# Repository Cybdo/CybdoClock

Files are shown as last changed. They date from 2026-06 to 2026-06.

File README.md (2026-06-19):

# CybdoClock!!

14 by 14 letter word clock / calendar / whatever, powered by esp32-c6!

27 past 5

Word clocks are arguably better and cooler than normal analog or digital clocks, but they are way too expensive comercially for a decent product, and even then there's not much customisation to it (the only one i could find was over 1000 dollars and could only show the time in 5 minute increments). CybdoClock was made to be able to show time down to the minute, in multiple formats, all while being customisable and allowing for different uses. The face plate can be swapped to show different languages or formats, and a calendar faceplate is coming soon!

# zine page
pdf at `./zine.pdf`


# Features
- native wifi, bluetooth and matter over thread capabilities
- support for custom faceplates with an easy to update firmware dict
- NTP time sync via wifi
- wall-mountable via command strips
- stand included for desktop use

# Assembly

The housing requires 4x M3 screws, as well as 4x M3 heat-set inserts, and 4x 5mm diameter, 2.5mm thick magnets.
Each faceplate also requires 4x 4x 5mm diameter, 2.5mm thick magnets, in the opposite polarity to the housing.
Magnets should be able to friction fit and stay in place, however a drop of superglue can aid in its placement.

# Usage
- flash circuitpython 10 onto the ESP-32 via USB-C.
- Copy the firmware folder onto the CIRCUITPY drive, and create settings.toml using settings.toml.example.
- install all requirements in requirements.txt using `circup install -r requirements.txt`

CybdoClock will now turn on and sync to NTP once connected to a USB power source!

# Firmware
CybdoClock runs off CircuitPython 10.x, and code can be found under `./firmware/`

# Technical Documentation

CybdoClock is powered by a 14x14 LED matrix. NOTE: CybdoClock refreshes vertically, and defaults to left -> right. This is a hardware limitation, and overrides in firmware could cause permanent damage to components.

## Shift Registers

While the provided firmware uses the adafruit library and pins, a custom firmware can interface with the pins by sending the following serial data:

| 0 | 1 | 2 | 3 | 4 | 5 | 6 | 7 | 8 | 9 | 10 | 11 | 12 | 13 | 14 | 15 | 16 | 17 | 18 | 19 | 20 | 21 | 22 | 23 | 24 | 25 | 26 | 27 | 28 | 29 | 30 | 31 |
|---|---|---|---|---|---|---|---|---|---|---|---|---|---|---|---|---|---|---|---|---|---|---|---|---|---|---|---|---|---|---|---|
| Row 14 | Row 13 | Row 12 | Row 11 | Row 10 | Row 9 | Row 8 | NC | Row 7 | Row 6 | Row 5 | Row 4 | Row 3 | Row 2 | Row 1 | NC | Col 14 | Col 13 | Col 12 | Col 11 | Col 10 | Col 9 | Col 8 | NC | Col 7 | Col 6 | Col 5 | Col 4 | Col 3 | Col 2 | Col 1 | NC |
## Schematics

Please note - the net labels for columns and rows do not reflect their physical layouts, nor does the layout of the matrix in the schematic
a pdf can be found at `./schematics.pdf`


## PCB


# Acknowledgements
 - [KiCad](https://www.kicad.org)
 - [Hack Club Fallout](https://fallout.hackclub.com)
 - [pcb2blender](https://github.com/30350n/pcb2blender)
 - [Blender](https://blender.org)
 - [CircuitPython](https://circuitpython.org/)

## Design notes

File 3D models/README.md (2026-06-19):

\# 3D Models

Everything should be able to print without supports, however the housing could turn out better if supports were enabled.

When printing the clock faceplate, pause the print at around 2-3 layers, and place a sheet of Tulle fabric over it, secured with either magnets or glue, and then continue printing. This keeps floating sections of text secured to the faceplate and enhances the legibility of the letters.

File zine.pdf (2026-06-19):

# CybdoClock

# A 14x14 ESP-32 powered word clock!

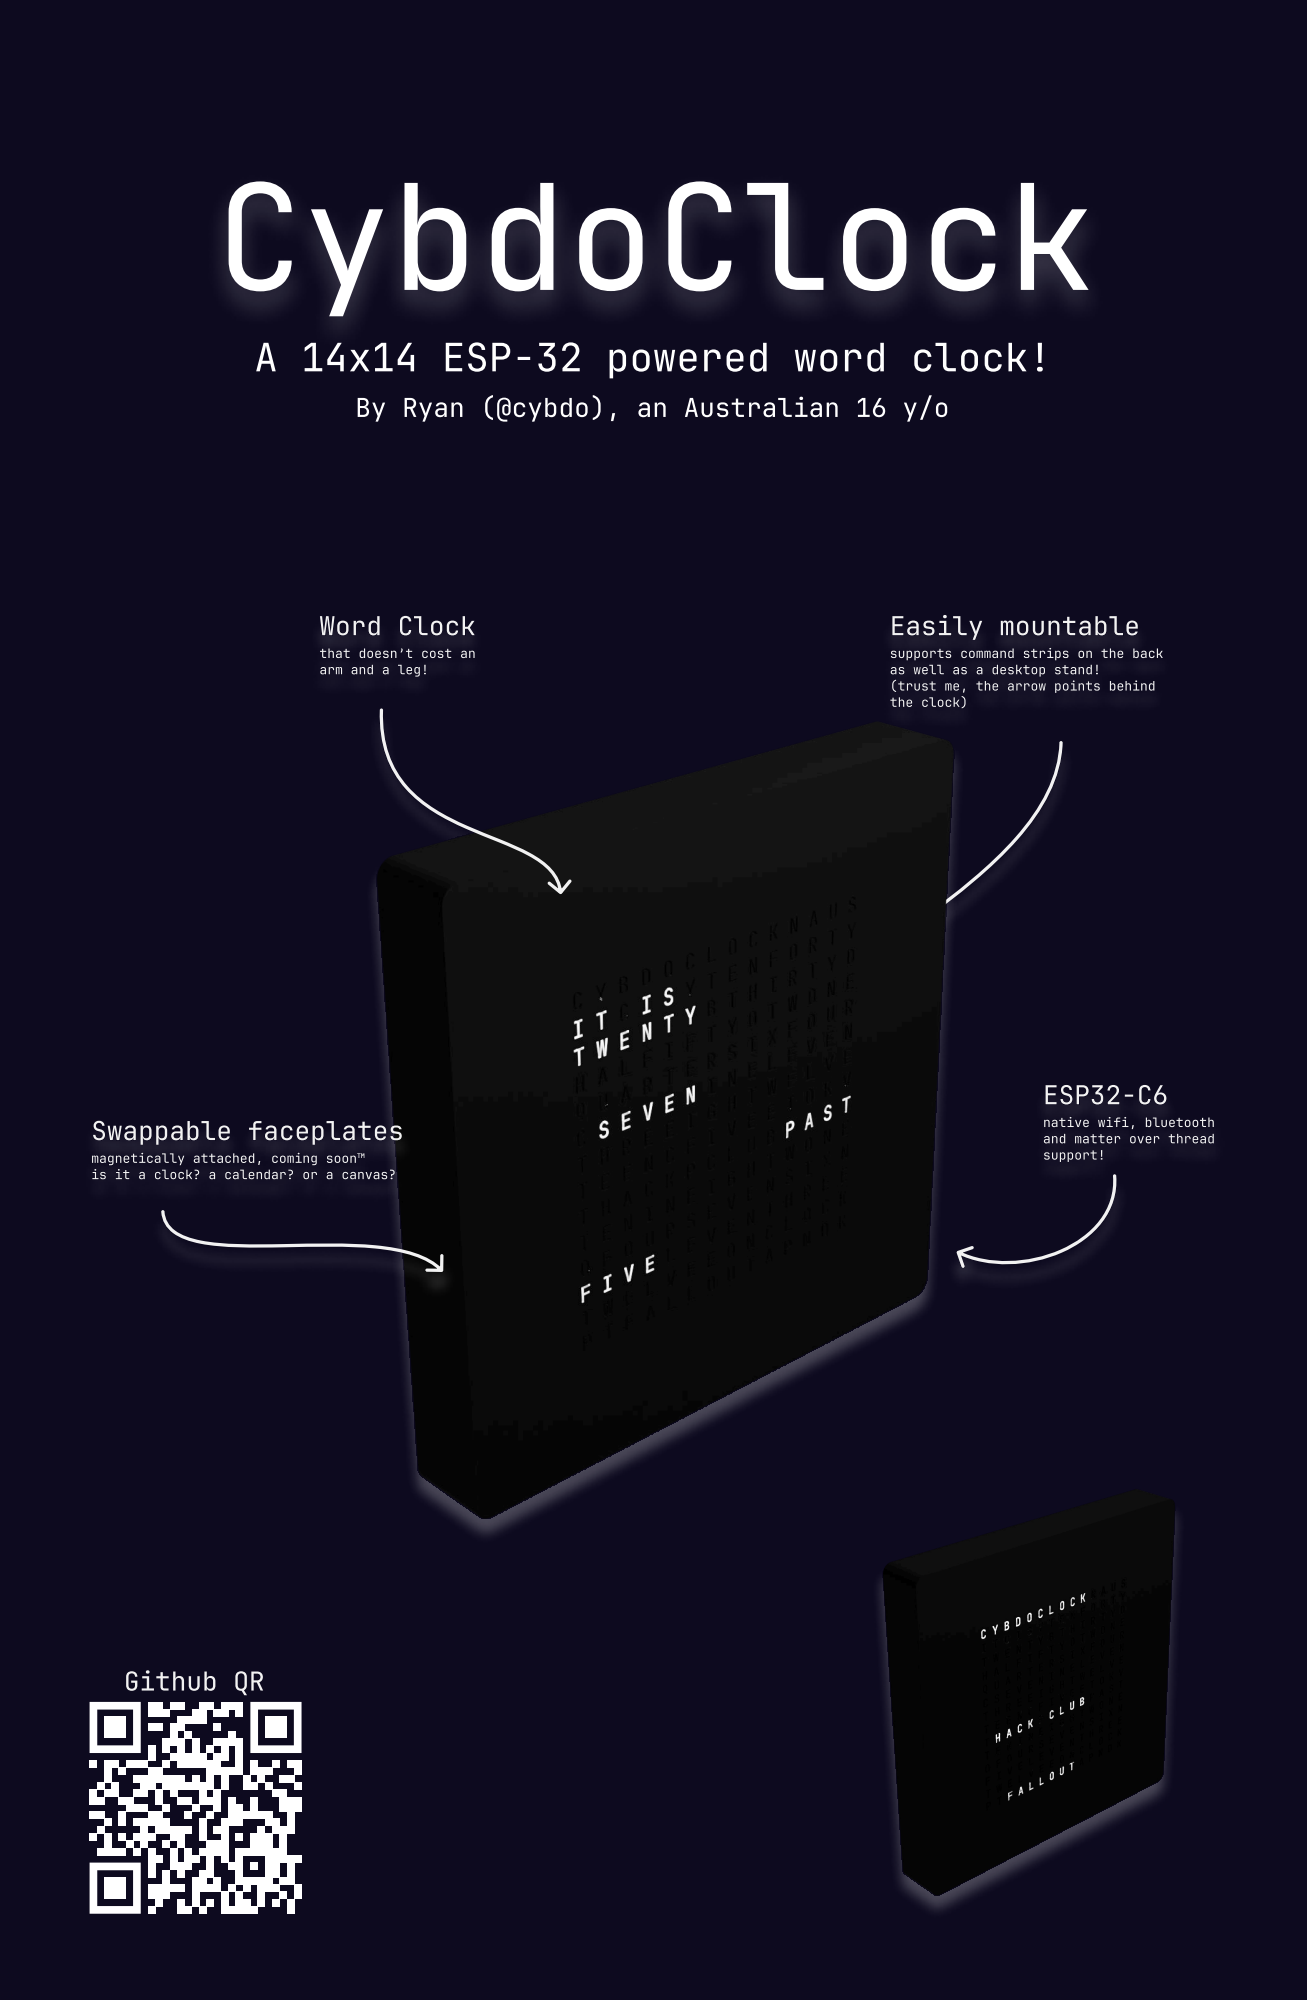
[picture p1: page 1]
Word Clock; Easily mountable; the clock); Swappable faceplates; ESP32-C6; Github QR

By Ryan (@cybdo), an Australian 16 y/o

that doesn’t cost an
arm and a leg!

supports command strips on the back
as well as a desktop stand!
(trust me, the arrow points behind

native wifi, bluetooth

and matter over thread
support!

magnetically attached, coming soon™

is it a clock? a calendar? or a canvas?

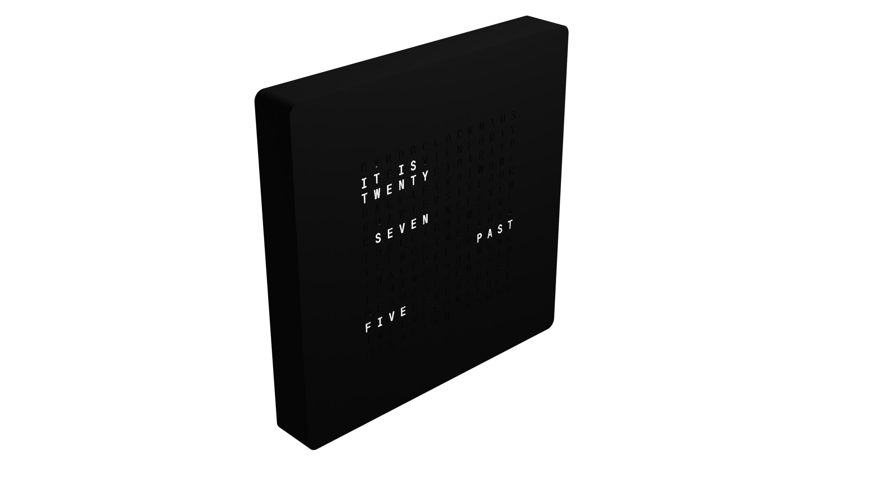
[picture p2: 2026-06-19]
Rendering/27 past 5.png

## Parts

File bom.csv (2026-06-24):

Item | Price ea (USD) | Qty | Price Total (USD) | Link | notes
components | 13.87 | 1 | 13.87 | https://lcsc.com | see lcsc-bom.xls and excl shipping
magnet (5mmx2.5mm) 10pk | 1 | 1 | 1 | https://www.aliexpress.com/item/1005011595343023.html?curPageLogUid=HDLwaCxZ9dYk&utparam-url=scene%3Asearch|query_from%3A|x_object_id%3A1005011595343023|_p_origin_prod%3A
M3 screw 100pcs | 1.25 | 1 | 1.25 | https://www.aliexpress.com/item/32869840993.html
M3 heat set insert | 1 | 1 | 1 | https://www.aliexpress.com/item/1005004870993068.html
Tulle Fabric | 9.81 | 1 | 9.81 | https://www.spotlightstores.com/en-au/p/plain-180-cm-my-special-day-tulle-fabric/BP80599805-black
PCB 5pcs | 25.57 | 1 | 25.57 | https://jlcpcb.com | including shipping
xiao esp-32 c6 | 1 | 1 | 1 | https://www.aliexpress.com/item/1005006987272421.html
 | Total: | 53.5

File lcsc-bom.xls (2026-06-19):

kicad-bom.csv |  |  |  |  |  |  |  |  |  | LCSC BOM Quotation
 |  |  |  |  |  |  |  |  |  | BOM Date Created：19/06/26 10:48:09 |  |  |  | BOM Export Date: 19/06/26 10:52:23 |  |  |  | The matching result is a real-time query result, availability and prices may fluctuate. Backorder items are estimated prices for your reference, please submit "Create Quote" to get the real price. All information is provided "as is" and is subject to change without notice. Any use made of the information provided is without recourse to LCSC and at the user's risk.
 |  |  |  |  |  |  |  |  |  | EST TOTAL :$13.87 |  |  |  | Website：https://www.lcsc.com/bom | https://www.lcsc.com/bom | https://www.lcsc.com/bom | https://www.lcsc.com/bom
Uploaded data |  |  |  |  |  |  |  |  |  | LCSC Matching Results
LCSC# | Mfr. | Mrf# | Description | Package | Value | Customer Part Number | Quantity | Target Price(USD) | Target Lead Time(Business Days) | Mrf# | Mfr. | Order Qty. | Unit Price(USD) | Ext.Price(USD) | LCSC# | Package | Min | Mult | SPQ | Availability | Stock Status | Customer Notes | Description | Matched status | Product Link
 |  |  | 100nF | C_0402_1005Metric_Pad0.74x0.62mm_HandSolder |  | C1 | 1 |  |  | GRM155R71H104KE14D | muRata | 50 | 0.0127 | 0.64 | C77020 | 0402 | 50 | 50 | 10000 | 10000 | In Stock |  | 100nF ±10% 50V Ceramic Capacitor X7R 0402 | Partial Matches | https://www.lcsc.com/product-detail/C77020.html
C7433012 |  |  | LED | LED_D5.0mm |  | D1, D2, D3, D4, D5, D6, D7, D8, D9, D10, D11, D12, D13, D14, D15 | 196 |  |  | DY-334UWC-26K | TONYU | 200 | 0.0464 | 9.28 | C7433012 | D=5mm | 10 | 10 | 500 | 830 | In Stock |  | Warm White LED Indication - Discrete 2.8V~3.4V D=5mm | Exact Matches | https://www.lcsc.com/product-detail/C7433012.html
 |  |  | ALS-PDIC144-6C/L378 | LED_D3.0mm |  | D197 | 1 |  |  | ALS-PDIC144-6C/L378 | EVERLIGHT | 5 | 0.2179 | 1.09 | C2943463 | Through Hole,D=3mm | 5 | 5 | 1000 | 29400 | In Stock |  | 1.8V~5.5V Through Hole,D=3mm Ambient Light, IR, UV Sensors RoHS | Partial Matches | https://www.lcsc.com/product-detail/C2943463.html
C504149 |  |  | CJL2301 | SOT-23-6_L2.9-W1.6-P0.95-LS2.8-BL |  | Q1, Q2, Q3, Q4, Q5, Q6, Q7 | 7 |  |  | CJL2301 | JSCJ | 10 | 0.0752 | 0.75 | C504149 | SOT-23-6L | 10 | 10 | 3000 | 10680 | In Stock |  | P-Channel 20V 2.3A 0.35W Surface Mount SOT-23-6L | Exact Matches | https://www.lcsc.com/product-detail/C504149.html
C22359228 |  |  | HSW6822 | SOT-23-6_L2.9-W1.6-P0.95-LS2.8-BL |  | Q8, Q9, Q10, Q11, Q12, Q13, Q14 | 7 |  |  | HSW6822 | HUASHUO | 10 | 0.0202 | 0.20 | C22359228 | SOT-23-6L | 10 | 10 | 3000 | 1950 | In Stock |  | N-Channel Array 20V 5A 1.7W Surface Mount SOT-23-6L | Exact Matches | https://www.lcsc.com/product-detail/C22359228.html
 |  |  | 28kR | R_0402_1005Metric_Pad0.72x0.64mm_HandSolder |  | R1 | 1 |  |  | FRC0402F2802TS | FOJAN | 100 | 0.0014 | 0.14 | C2998150 | 0402 | 100 | 100 | 10000 | 244400 | In Stock |  | 28kΩ ±1% 62.5mW 0402 Thick Film Resistor | Partial Matches | https://www.lcsc.com/product-detail/C2998150.html
 |  |  | 220R | R_0402_1005Metric_Pad0.72x0.64mm_HandSolder |  | R2, R3, R4, R5, R6, R7, R8, R9, R10, R11, R12, R13, R14, R15 | 14 |  |  | RC0402FR-07220RL | YAGEO | 100 | 0.0010 | 0.10 | C112291 | 0402 | 100 | 100 | 10000 | 13100 | In Stock |  | 220Ω 62.5mW 50V Thick Film Resistor ±100ppm/℃ ±1% 0402 Chip Resistor - Surface Mount RoHS | Partial Matches | https://www.lcsc.com/product-detail/C112291.html
 |  |  | 3296W-1-103LF | Potentiometer_Bourns_3296W_Vertical |  | RV1 | 1 |  |  | 3296W-1-103LF | BOURNS | 1 | 0.8721 | 0.87 | C34846 | SIP-3P,9.5x4.8mm | 1 | 1 | 50 | 8985 | In Stock |  | 10kΩ ±10% 500mW SIP-3P,9.5x4.8mm Potentiometers, Variable Resistors | Partial Matches | https://www.lcsc.com/product-detail/C34846.html
 |  |  | XIAO-ESP32-C6-DIP | XIAO-ESP32-C6-DIP |  | U1 | 1 |  |  | -(The data has been deleted.) | - | - | - | - | - | - | - | - | - | - | - | - | - | -
 |  |  | 74HCT595 | SOIC-16_3.9x9.9mm_P1.27mm |  | U2, U3, U4, U5 | 4 |  |  | 74HCT595D | MDD(Microdiode Semiconductor) | 4 | 0.1997 | 0.80 | C52140404 | SOP-16L | 1 | 1 | 2500 | 5335 | In Stock |  | 2.7V~5.5V 35mA 30ns@4.5V,15pF Serial-to-Serial or Parallel SOP-16L Shift Registers RoHS | Partial Matches | https://www.lcsc.com/product-detail/C52140404.html

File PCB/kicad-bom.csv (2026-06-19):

Id | Designator | Footprint | Quantity | Designation | Supplier and ref
1 | C1 | C_0402_1005Metric_Pad0.74x0.62mm_HandSolder | 1 | 100nF
2 | D1, D2, D3, D4, D5, D6, D7, D8, D9, D10, D11, D12, D13, D14, D15, D16, D17, D18, D19, D20, D21, D22, D23, D24, D25, D26, D27, D28, D29, D30, D31, D32, D33, D34, D35, D36, D37, D38, D39, D40, D41, D42, D43, D44, D45, D46, D47, D48, D49, D50, D51, D52, D53, D54, D55, D56, D57, D58, D59, D60, D61, D62, D63, D64, D65, D66, D67, D68, D69, D70, D71, D72, D73, D74, D75, D76, D77, D78, D79, D80, D81, D82, D83, D84, D85, D86, D87, D88, D89, D90, D91, D92, D93, D94, D95, D96, D97, D98, D99, D100, D101, D102, D103, D104, D105, D106, D107, D108, D109, D110, D111, D112, D113, D114, D115, D116, D117, D118, D119, D120, D121, D122, D123, D124, D125, D126, D127, D128, D129, D130, D131, D132, D133, D134, D135, D136, D137, D138, D139, D140, D141, D142, D143, D144, D145, D146, D147, D148, D149, D150, D151, D152, D153, D154, D155, D156, D157, D158, D159, D160, D161, D162, D163, D164, D165, D166, D167, D168, D169, D170, D171, D172, D173, D174, D175, D176, D177, D178, D179, D180, D181, D182, D183, D184, D185, D186, D187, D188, D189, D190, D191, D192, D193, D194, D195, D196 | LED_D5.0mm | 196 | LED
3 | D197 | LED_D3.0mm | 1 | ALS-PDIC144-6C/L378
4 | Q1, Q2, Q3, Q4, Q5, Q6, Q7 | SOT-23-6_L2.9-W1.6-P0.95-LS2.8-BL | 7 | CJL2301
5 | Q8, Q9, Q10, Q11, Q12, Q13, Q14 | SOT-23-6_L2.9-W1.6-P0.95-LS2.8-BL | 7 | HSW6822
6 | R1 | R_0402_1005Metric_Pad0.72x0.64mm_HandSolder | 1 | 28kR
7 | R2, R3, R4, R5, R6, R7, R8, R9, R10, R11, R12, R13, R14, R15 | R_0402_1005Metric_Pad0.72x0.64mm_HandSolder | 14 | 220R
8 | RV1 | Potentiometer_Bourns_3296W_Vertical | 1 | 3296W-1-103LF
9 | U1 | XIAO-ESP32-C6-DIP | 1 | XIAO-ESP32-C6-DIP
10 | U2, U3, U4, U5 | SOIC-16_3.9x9.9mm_P1.27mm | 4 | 74HCT595

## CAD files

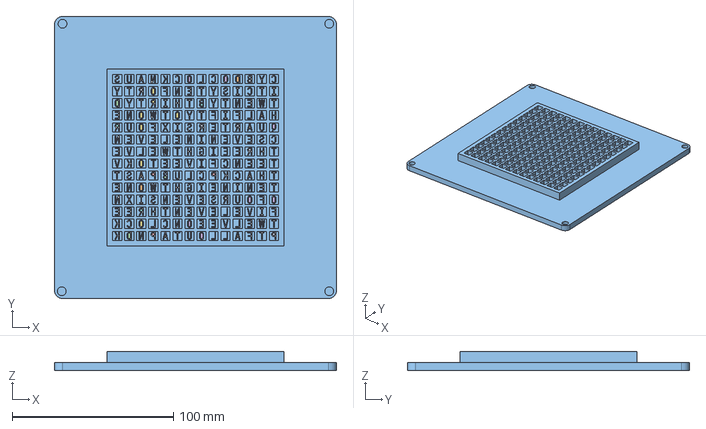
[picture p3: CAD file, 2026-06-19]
3D models/Clock Faceplate.step
175.0 x 175.0 x 12.0 mm

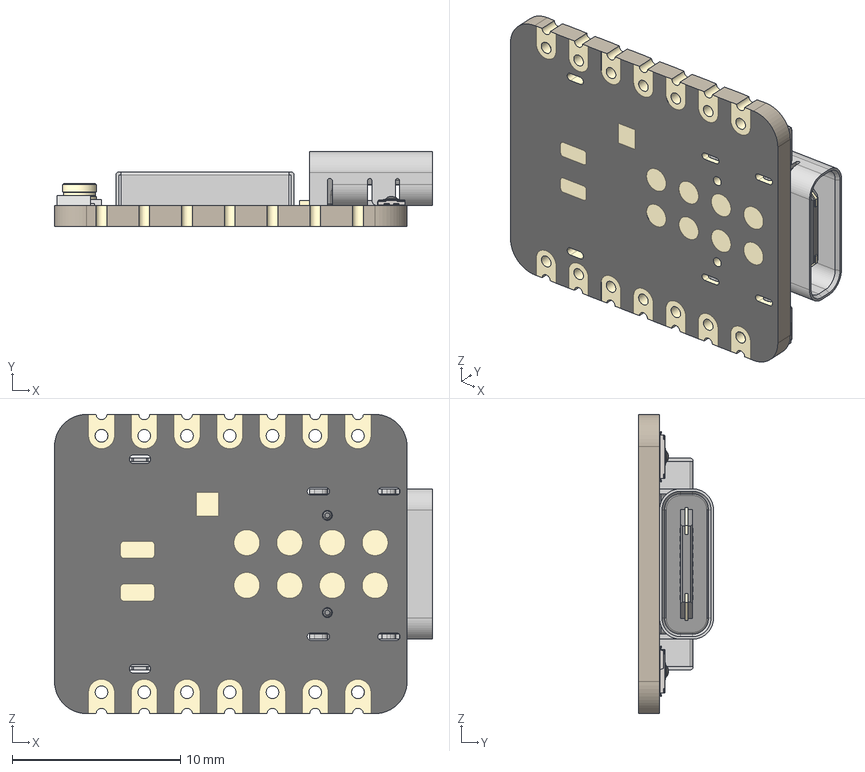
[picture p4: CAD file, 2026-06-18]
PCB/imports/Seeed Studio XIAO ESP32-C6.step
22.5 x 4.46 x 17.8 mm
BOSS-EXTRUDE14_8_
BOSS-EXTRUDE7_4_
BOSS-EXTRUDE7_3_
BOSS-EXTRUDE14_4_
BOSS-EXTRUDE14_2_
BOSS-EXTRUDE14_11_
BOSS-EXTRUDE7_7_
BOSS-EXTRUDE14_9_
BOSS-EXTRUDE14_3_
BOSS-EXTRUDE14_7_
MIRROR2
BOSS-EXTRUDE14_5_
BOSS-EXTRUDE14_12_
BOSS-EXTRUDE7_8_
BOSS-EXTRUDE7_1_
BOSS-EXTRUDE14_10_
BOSS-EXTRUDE7_9_
BOSS-EXTRUDE14_6_
BOSS-EXTRUDE14_1_
BOSS-EXTRUDE7_6_
BOSS-EXTRUDE7_2_
CUT-EXTRUDE5
BOSS-EXTRUDE7_5_
U.FL Connector v1
Shield
SKTAAAE010 x 2
KH5220-A36 (Ceramic Antenna) v2

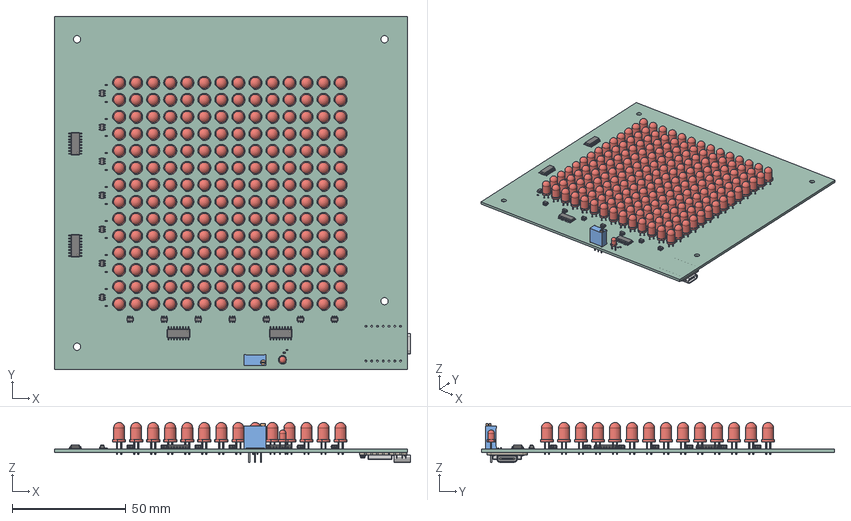
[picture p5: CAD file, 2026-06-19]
PCB/pcb.step
156.5 x 155.0 x 17.6 mm
LED_D5.0mm x 196
SOT-23-6_L2.9-W1.6-H1.5-LS2.8-P0.95 x 14
R_0402_1005Metric x 15
C_0402_1005Metric
Potentiometer_Bourns_3296W_Vertical
LED_D3.0mm
SOIC-16_3.9x9.9mm_P1.27mm x 4
BOSS-EXTRUDE14_8_
BOSS-EXTRUDE7_4_
BOSS-EXTRUDE7_3_
BOSS-EXTRUDE14_4_
BOSS-EXTRUDE14_2_
BOSS-EXTRUDE14_11_
BOSS-EXTRUDE7_7_
BOSS-EXTRUDE14_9_
BOSS-EXTRUDE14_3_
BOSS-EXTRUDE14_7_
MIRROR2
BOSS-EXTRUDE14_5_
BOSS-EXTRUDE14_12_
BOSS-EXTRUDE7_8_
BOSS-EXTRUDE7_1_
BOSS-EXTRUDE14_10_
BOSS-EXTRUDE7_9_
BOSS-EXTRUDE14_6_
BOSS-EXTRUDE14_1_
BOSS-EXTRUDE7_6_
BOSS-EXTRUDE7_2_
CUT-EXTRUDE5
BOSS-EXTRUDE7_5_
U.FL Connector v1
Shield
SKTAAAE010 v1 x 2
KH5220-A36 (Ceramic Antenna) v2
CybdoClock_PCB

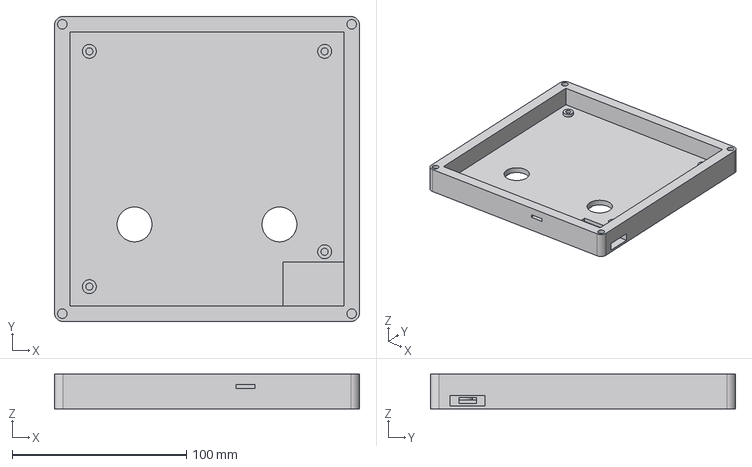
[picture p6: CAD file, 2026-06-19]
3D models/housing.step
175.0 x 175.0 x 20.0 mm

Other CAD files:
3D models/Faceplate Template.step

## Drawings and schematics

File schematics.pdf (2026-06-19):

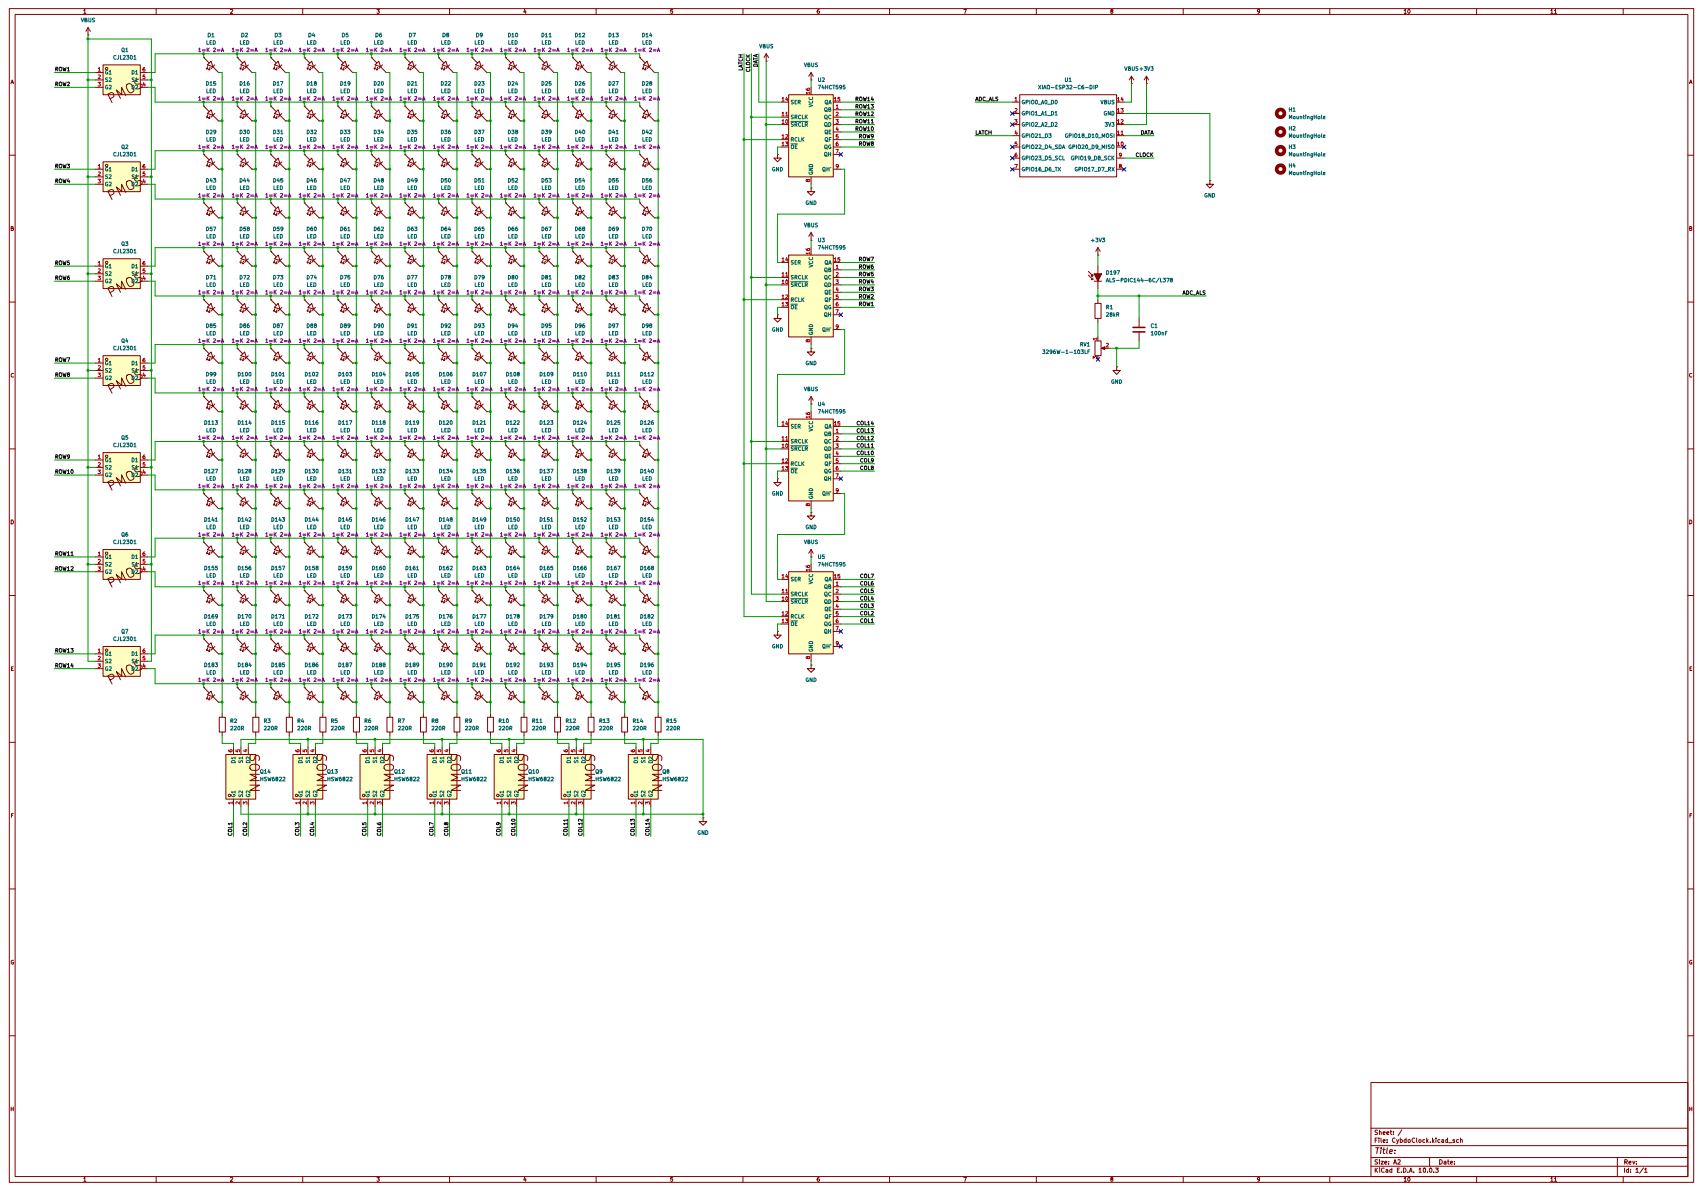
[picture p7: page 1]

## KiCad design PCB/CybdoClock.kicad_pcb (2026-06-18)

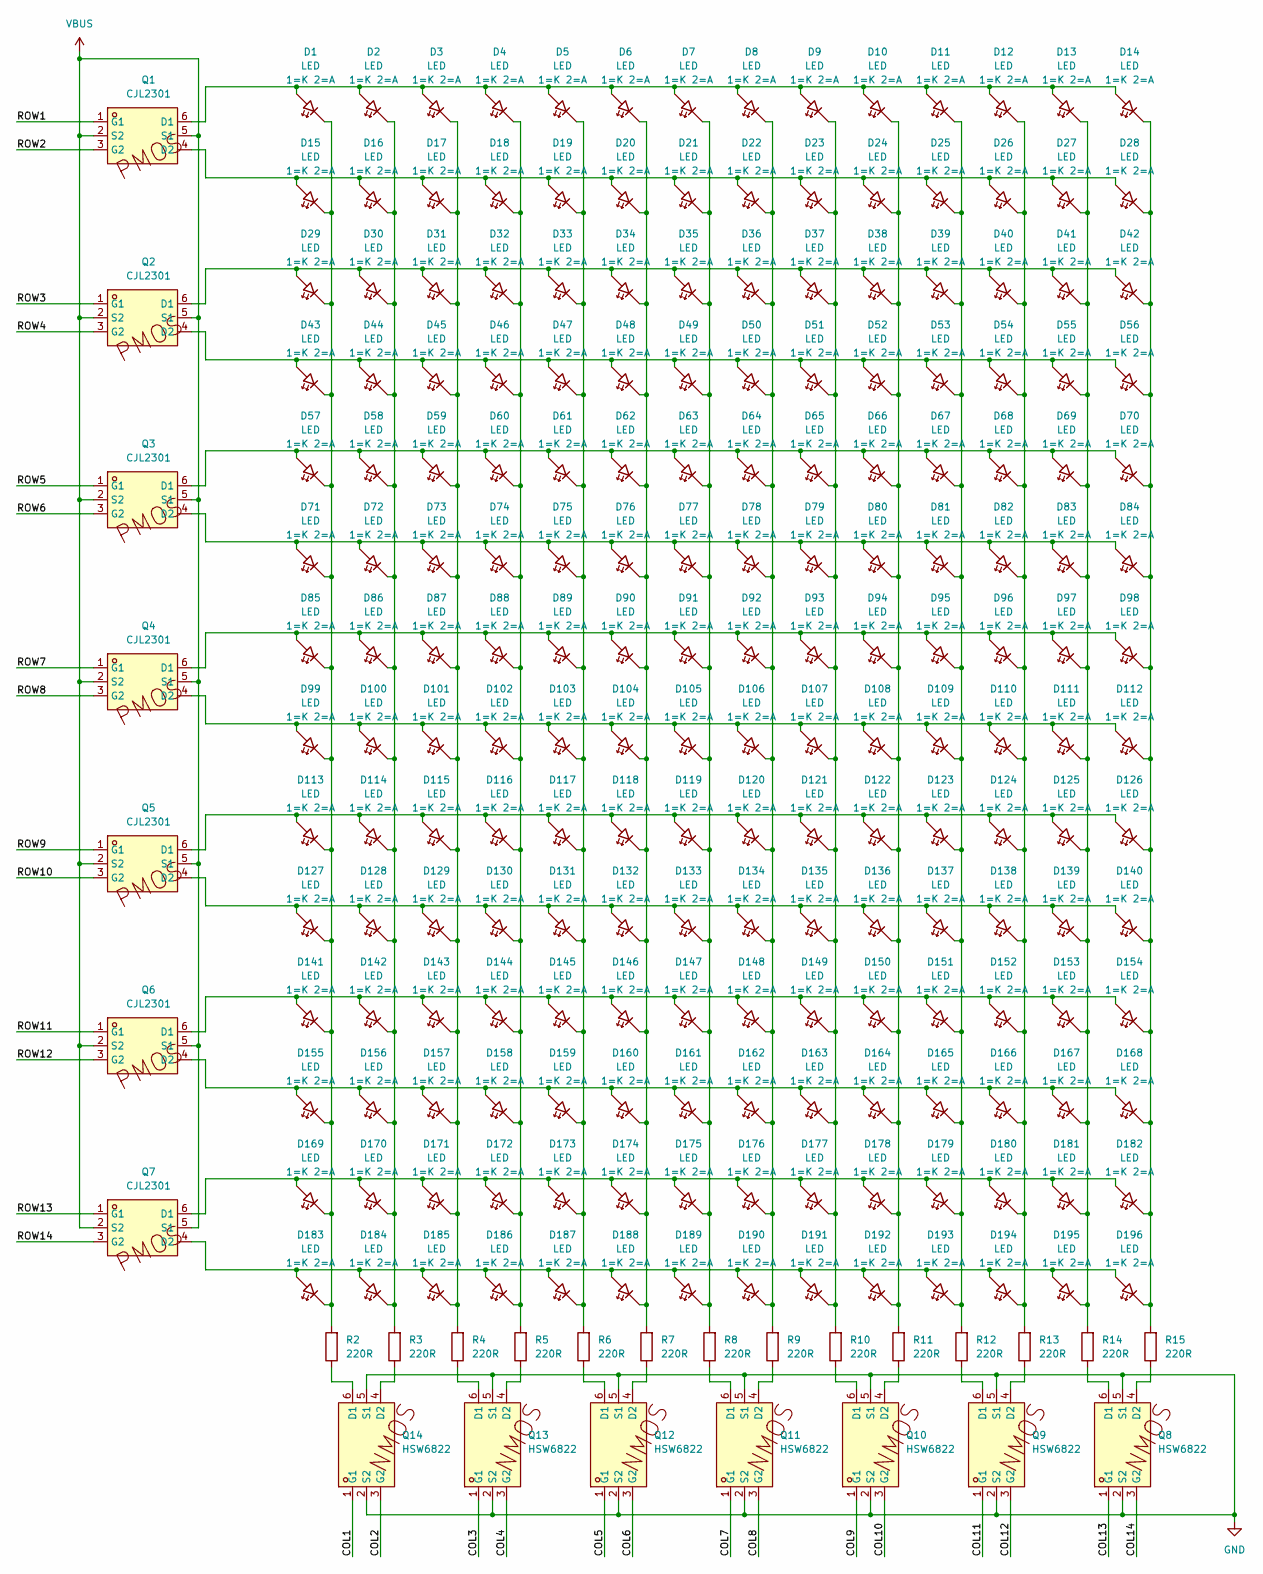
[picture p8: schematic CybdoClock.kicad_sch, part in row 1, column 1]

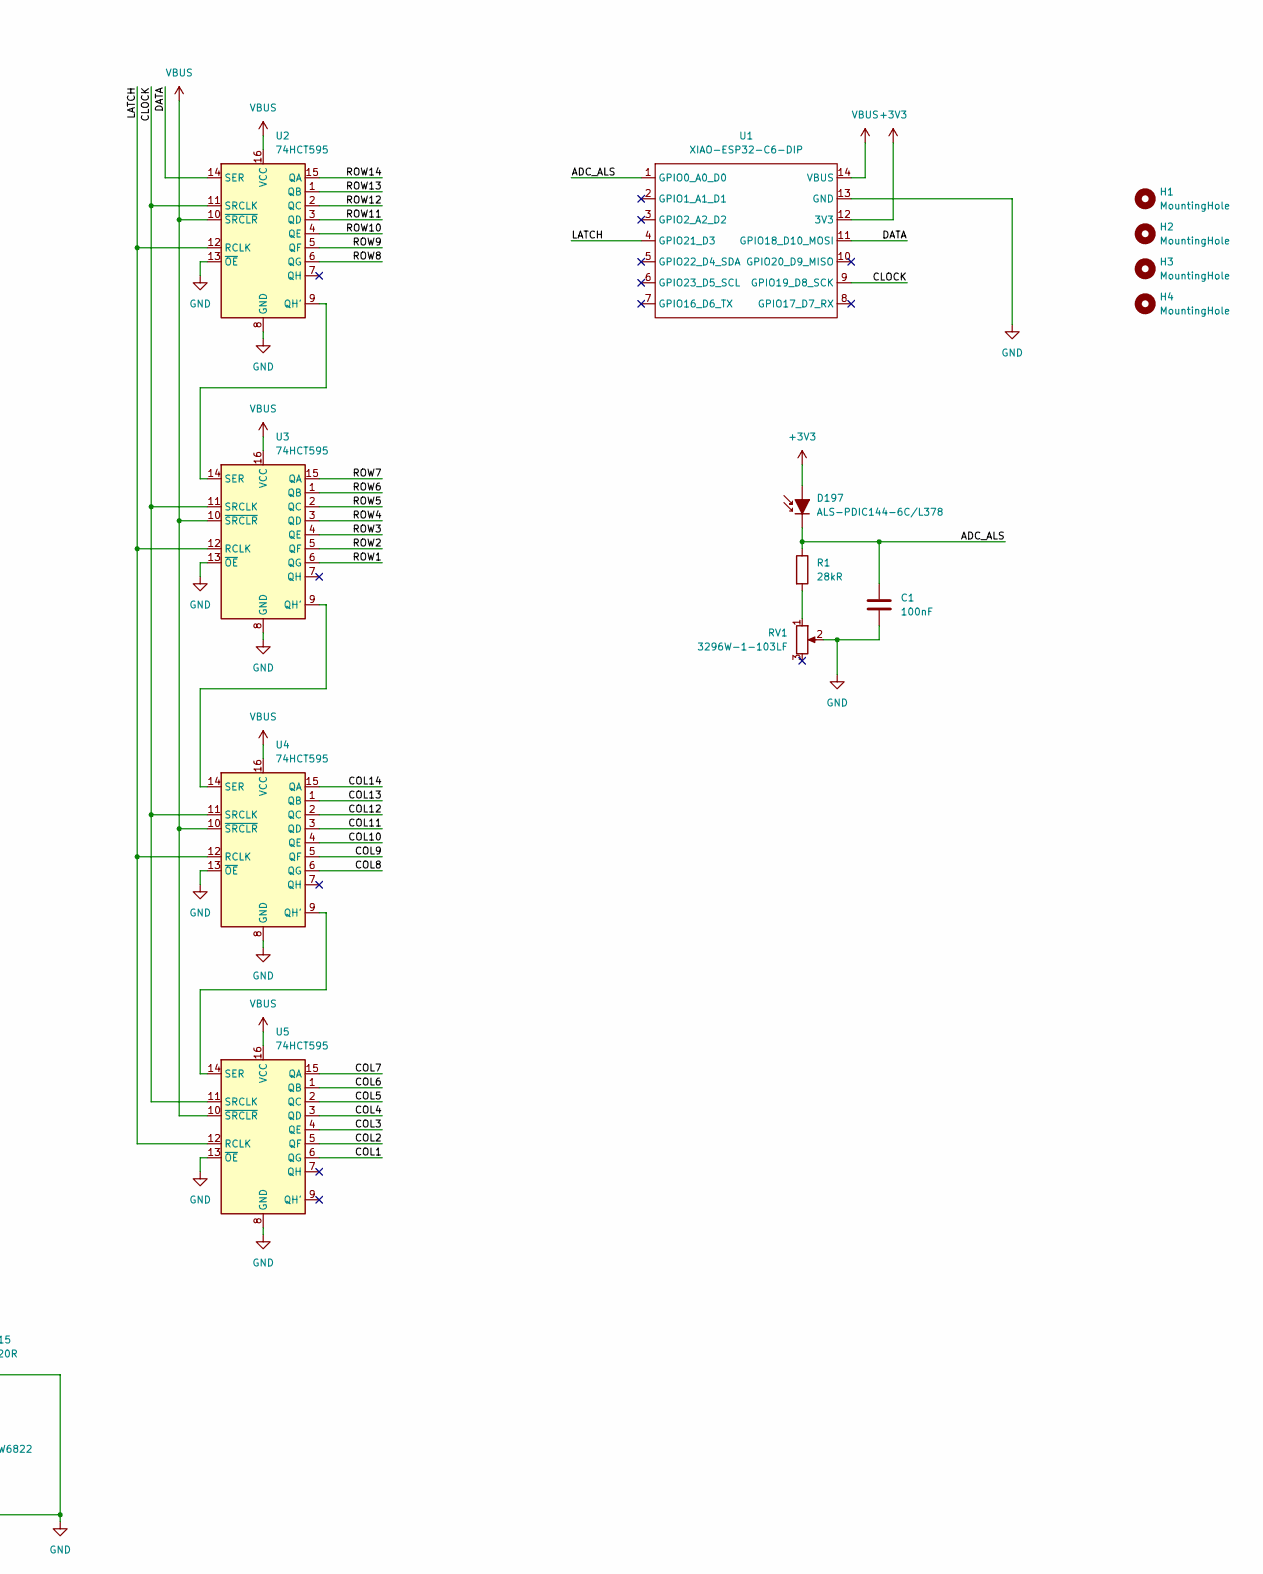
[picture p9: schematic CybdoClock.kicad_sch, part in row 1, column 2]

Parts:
C1: 100nF; C_0402_1005Metric_Pad0.74x0.62mm_HandSolder
D1, D2, D3, D4, D5, D6, D7, D8, D9, D10, D11, D12, D13, D14, D15, D16, D17, D18, D19, D20, D21, D22, D23, D24, D25, D26, D27, D28, D29, D30, D31, D32, D33, D34, D35, D36, D37, D38, D39, D40, D41, D42, D43, D44, D45, D46, D47, D48, D49, D50, D51, D52, D53, D54, D55, D56, D57, D58, D59, D60, D61, D62, D63, D64, D65, D66, D67, D68, D69, D70, D71, D72, D73, D74, D75, D76, D77, D78, D79, D80, D81, D82, D83, D84, D85, D86, D87, D88, D89, D90, D91, D92, D93, D94, D95, D96, D97, D98, D99, D100, D101, D102, D103, D104, D105, D106, D107, D108, D109, D110, D111, D112, D113, D114, D115, D116, D117, D118, D119, D120, D121, D122, D123, D124, D125, D126, D127, D128, D129, D130, D131, D132, D133, D134, D135, D136, D137, D138, D139, D140, D141, D142, D143, D144, D145, D146, D147, D148, D149, D150, D151, D152, D153, D154, D155, D156, D157, D158, D159, D160, D161, D162, D163, D164, D165, D166, D167, D168, D169, D170, D171, D172, D173, D174, D175, D176, D177, D178, D179, D180, D181, D182, D183, D184, D185, D186, D187, D188, D189, D190, D191, D192, D193, D194, D195, D196: LED; LED_D5.0mm
D197: ALS-PDIC144-6C/L378; LED_D3.0mm
H1, H2, H3, H4: MountingHole; MountingHole_3.2mm_M3
Q1, Q2, Q3, Q4, Q5, Q6, Q7: CJL2301; SOT-23-6_L2.9-W1.6-P0.95-LS2.8-BL; MPN CJL2301; LCSC Part C504149
Q8, Q9, Q10, Q11, Q12, Q13, Q14: HSW6822; SOT-23-6_L2.9-W1.6-P0.95-LS2.8-BL; MPN HSW6822; LCSC Part C22359228
R1: 28kR; R_0402_1005Metric_Pad0.72x0.64mm_HandSolder
R2, R3, R4, R5, R6, R7, R8, R9, R10, R11, R12, R13, R14, R15: 220R; R_0402_1005Metric_Pad0.72x0.64mm_HandSolder
RV1: 3296W-1-103LF; Potentiometer_Bourns_3296W_Vertical
U1: XIAO-ESP32-C6-DIP
U2, U3, U4, U5: 74HCT595; SOIC-16_3.9x9.9mm_P1.27mm

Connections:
+3V3: D197.2 (A), U1.12 (3V3)
/ADC_ALS: C1.1, D197.1 (K), R1.1, U1.1 (GPIO0_A0_D0)
/CLOCK: U1.9 (GPIO19_D8_SCK), U2.11 (SRCLK), U3.11 (SRCLK), U4.11 (SRCLK), U5.11 (SRCLK)
/COL1: Q14.1 (G1), U5.6 (QG)
/COL2: Q14.3 (G2), U5.5 (QF)
/COL3: Q13.1 (G1), U5.4 (QE)
/COL4: Q13.3 (G2), U5.3 (QD)
/COL5: Q12.1 (G1), U5.2 (QC)
/COL6: Q12.3 (G2), U5.1 (QB)
/COL7: Q11.1 (G1), U5.15 (QA)
/COL8: Q11.3 (G2), U4.6 (QG)
/COL9: Q10.1 (G1), U4.5 (QF)
/COL10: Q10.3 (G2), U4.4 (QE)
/COL11: Q9.1 (G1), U4.3 (QD)
/COL12: Q9.3 (G2), U4.2 (QC)
/COL13: Q8.1 (G1), U4.1 (QB)
/COL14: Q8.3 (G2), U4.15 (QA)
/DATA: U1.11 (GPIO18_D10_MOSI), U2.14 (SER)
/LATCH: U1.4 (GPIO21_D3), U2.12 (RCLK), U3.12 (RCLK), U4.12 (RCLK), U5.12 (RCLK)
/ROW1: Q1.1 (G1), U3.6 (QG)
/ROW2: Q1.3 (G2), U3.5 (QF)
/ROW3: Q2.1 (G1), U3.4 (QE)
/ROW4: Q2.3 (G2), U3.3 (QD)
/ROW5: Q3.1 (G1), U3.2 (QC)
/ROW6: Q3.3 (G2), U3.1 (QB)
/ROW7: Q4.1 (G1), U3.15 (QA)
/ROW8: Q4.3 (G2), U2.6 (QG)
/ROW9: Q5.1 (G1), U2.5 (QF)
/ROW10: Q5.3 (G2), U2.4 (QE)
/ROW11: Q6.1 (G1), U2.3 (QD)
/ROW12: Q6.3 (G2), U2.2 (QC)
/ROW13: Q7.1 (G1), U2.1 (QB)
/ROW14: Q7.3 (G2), U2.15 (QA)
GND: C1.2, Q8.2 (S2), Q8.5 (S1), Q9.2 (S2), Q9.5 (S1), Q10.2 (S2), Q10.5 (S1), Q11.2 (S2), Q11.5 (S1), Q12.2 (S2), Q12.5 (S1), Q13.2 (S2), Q13.5 (S1), Q14.2 (S2), Q14.5 (S1), RV1.2, U1.13 (GND), U2.8 (GND), U2.13 (~OE), U3.8 (GND), U3.13 (~OE), U4.8 (GND), U4.13 (~OE), U5.8 (GND), U5.13 (~OE)
unnamed: D1.2 (A), D2.2 (A), D3.2 (A), D4.2 (A), D5.2 (A), D6.2 (A), D7.2 (A), D8.2 (A), D9.2 (A), D10.2 (A), D11.2 (A), D12.2 (A), D13.2 (A), D14.2 (A), Q1.6 (D1)
unnamed: D1.1 (K), D15.1 (K), D29.1 (K), D43.1 (K), D57.1 (K), D71.1 (K), D85.1 (K), D99.1 (K), D113.1 (K), D127.1 (K), D141.1 (K), D155.1 (K), D169.1 (K), D183.1 (K), R2.2
unnamed: D10.1 (K), D24.1 (K), D38.1 (K), D52.1 (K), D66.1 (K), D80.1 (K), D94.1 (K), D108.1 (K), D122.1 (K), D136.1 (K), D150.1 (K), D164.1 (K), D178.1 (K), D192.1 (K), R11.2
unnamed: D15.2 (A), D16.2 (A), D17.2 (A), D18.2 (A), D19.2 (A), D20.2 (A), D21.2 (A), D22.2 (A), D23.2 (A), D24.2 (A), D25.2 (A), D26.2 (A), D27.2 (A), D28.2 (A), Q1.4 (D2)
unnamed: D29.2 (A), D30.2 (A), D31.2 (A), D32.2 (A), D33.2 (A), D34.2 (A), D35.2 (A), D36.2 (A), D37.2 (A), D38.2 (A), D39.2 (A), D40.2 (A), D41.2 (A), D42.2 (A), Q2.6 (D1)
unnamed: D43.2 (A), D44.2 (A), D45.2 (A), D46.2 (A), D47.2 (A), D48.2 (A), D49.2 (A), D50.2 (A), D51.2 (A), D52.2 (A), D53.2 (A), D54.2 (A), D55.2 (A), D56.2 (A), Q2.4 (D2)
unnamed: D57.2 (A), D58.2 (A), D59.2 (A), D60.2 (A), D61.2 (A), D62.2 (A), D63.2 (A), D64.2 (A), D65.2 (A), D66.2 (A), D67.2 (A), D68.2 (A), D69.2 (A), D70.2 (A), Q3.6 (D1)
unnamed: D71.2 (A), D72.2 (A), D73.2 (A), D74.2 (A), D75.2 (A), D76.2 (A), D77.2 (A), D78.2 (A), D79.2 (A), D80.2 (A), D81.2 (A), D82.2 (A), D83.2 (A), D84.2 (A), Q3.4 (D2)
unnamed: D85.2 (A), D86.2 (A), D87.2 (A), D88.2 (A), D89.2 (A), D90.2 (A), D91.2 (A), D92.2 (A), D93.2 (A), D94.2 (A), D95.2 (A), D96.2 (A), D97.2 (A), D98.2 (A), Q4.6 (D1)
unnamed: D99.2 (A), D100.2 (A), D101.2 (A), D102.2 (A), D103.2 (A), D104.2 (A), D105.2 (A), D106.2 (A), D107.2 (A), D108.2 (A), D109.2 (A), D110.2 (A), D111.2 (A), D112.2 (A), Q4.4 (D2)
unnamed: D2.1 (K), D16.1 (K), D30.1 (K), D44.1 (K), D58.1 (K), D72.1 (K), D86.1 (K), D100.1 (K), D114.1 (K), D128.1 (K), D142.1 (K), D156.1 (K), D170.1 (K), D184.1 (K), R3.2
unnamed: D3.1 (K), D17.1 (K), D31.1 (K), D45.1 (K), D59.1 (K), D73.1 (K), D87.1 (K), D101.1 (K), D115.1 (K), D129.1 (K), D143.1 (K), D157.1 (K), D171.1 (K), D185.1 (K), R4.2
unnamed: D4.1 (K), D18.1 (K), D32.1 (K), D46.1 (K), D60.1 (K), D74.1 (K), D88.1 (K), D102.1 (K), D116.1 (K), D130.1 (K), D144.1 (K), D158.1 (K), D172.1 (K), D186.1 (K), R5.2
unnamed: D5.1 (K), D19.1 (K), D33.1 (K), D47.1 (K), D61.1 (K), D75.1 (K), D89.1 (K), D103.1 (K), D117.1 (K), D131.1 (K), D145.1 (K), D159.1 (K), D173.1 (K), D187.1 (K), R6.2
unnamed: D6.1 (K), D20.1 (K), D34.1 (K), D48.1 (K), D62.1 (K), D76.1 (K), D90.1 (K), D104.1 (K), D118.1 (K), D132.1 (K), D146.1 (K), D160.1 (K), D174.1 (K), D188.1 (K), R7.2
unnamed: D7.1 (K), D21.1 (K), D35.1 (K), D49.1 (K), D63.1 (K), D77.1 (K), D91.1 (K), D105.1 (K), D119.1 (K), D133.1 (K), D147.1 (K), D161.1 (K), D175.1 (K), D189.1 (K), R8.2
unnamed: D8.1 (K), D22.1 (K), D36.1 (K), D50.1 (K), D64.1 (K), D78.1 (K), D92.1 (K), D106.1 (K), D120.1 (K), D134.1 (K), D148.1 (K), D162.1 (K), D176.1 (K), D190.1 (K), R9.2
unnamed: D9.1 (K), D23.1 (K), D37.1 (K), D51.1 (K), D65.1 (K), D79.1 (K), D93.1 (K), D107.1 (K), D121.1 (K), D135.1 (K), D149.1 (K), D163.1 (K), D177.1 (K), D191.1 (K), R10.2
unnamed: D11.1 (K), D25.1 (K), D39.1 (K), D53.1 (K), D67.1 (K), D81.1 (K), D95.1 (K), D109.1 (K), D123.1 (K), D137.1 (K), D151.1 (K), D165.1 (K), D179.1 (K), D193.1 (K), R12.2
unnamed: D12.1 (K), D26.1 (K), D40.1 (K), D54.1 (K), D68.1 (K), D82.1 (K), D96.1 (K), D110.1 (K), D124.1 (K), D138.1 (K), D152.1 (K), D166.1 (K), D180.1 (K), D194.1 (K), R13.2
unnamed: D13.1 (K), D27.1 (K), D41.1 (K), D55.1 (K), D69.1 (K), D83.1 (K), D97.1 (K), D111.1 (K), D125.1 (K), D139.1 (K), D153.1 (K), D167.1 (K), D181.1 (K), D195.1 (K), R14.2
unnamed: D14.1 (K), D28.1 (K), D42.1 (K), D56.1 (K), D70.1 (K), D84.1 (K), D98.1 (K), D112.1 (K), D126.1 (K), D140.1 (K), D154.1 (K), D168.1 (K), D182.1 (K), D196.1 (K), R15.2
unnamed: D113.2 (A), D114.2 (A), D115.2 (A), D116.2 (A), D117.2 (A), D118.2 (A), D119.2 (A), D120.2 (A), D121.2 (A), D122.2 (A), D123.2 (A), D124.2 (A), D125.2 (A), D126.2 (A), Q5.6 (D1)
unnamed: D127.2 (A), D128.2 (A), D129.2 (A), D130.2 (A), D131.2 (A), D132.2 (A), D133.2 (A), D134.2 (A), D135.2 (A), D136.2 (A), D137.2 (A), D138.2 (A), D139.2 (A), D140.2 (A), Q5.4 (D2)
unnamed: D141.2 (A), D142.2 (A), D143.2 (A), D144.2 (A), D145.2 (A), D146.2 (A), D147.2 (A), D148.2 (A), D149.2 (A), D150.2 (A), D151.2 (A), D152.2 (A), D153.2 (A), D154.2 (A), Q6.6 (D1)
unnamed: D155.2 (A), D156.2 (A), D157.2 (A), D158.2 (A), D159.2 (A), D160.2 (A), D161.2 (A), D162.2 (A), D163.2 (A), D164.2 (A), D165.2 (A), D166.2 (A), D167.2 (A), D168.2 (A), Q6.4 (D2)
unnamed: D169.2 (A), D170.2 (A), D171.2 (A), D172.2 (A), D173.2 (A), D174.2 (A), D175.2 (A), D176.2 (A), D177.2 (A), D178.2 (A), D179.2 (A), D180.2 (A), D181.2 (A), D182.2 (A), Q7.6 (D1)
unnamed: D183.2 (A), D184.2 (A), D185.2 (A), D186.2 (A), D187.2 (A), D188.2 (A), D189.2 (A), D190.2 (A), D191.2 (A), D192.2 (A), D193.2 (A), D194.2 (A), D195.2 (A), D196.2 (A), Q7.4 (D2)
unnamed: Q8.6 (D1), R14.1
unnamed: Q8.4 (D2), R15.1
unnamed: Q9.6 (D1), R12.1
unnamed: Q9.4 (D2), R13.1
unnamed: Q10.6 (D1), R10.1
unnamed: Q10.4 (D2), R11.1
unnamed: Q11.6 (D1), R8.1
unnamed: Q11.4 (D2), R9.1
unnamed: Q12.6 (D1), R6.1
unnamed: Q12.4 (D2), R7.1
unnamed: Q13.6 (D1), R4.1
unnamed: Q13.4 (D2), R5.1
unnamed: Q14.6 (D1), R2.1
unnamed: Q14.4 (D2), R3.1
unnamed: R1.2, RV1.1
unnamed: U2.9 (QH'), U3.14 (SER)
unnamed: U3.9 (QH'), U4.14 (SER)
unnamed: U4.9 (QH'), U5.14 (SER)
VBUS: Q1.2 (S2), Q1.5 (S1), Q2.2 (S2), Q2.5 (S1), Q3.2 (S2), Q3.5 (S1), Q4.2 (S2), Q4.5 (S1), Q5.2 (S2), Q5.5 (S1), Q6.2 (S2), Q6.5 (S1), Q7.2 (S2), Q7.5 (S1), U1.14 (VBUS), U2.10 (~SRCLR), U2.16 (VCC), U3.10 (~SRCLR), U3.16 (VCC), U4.10 (~SRCLR), U4.16 (VCC), U5.10 (~SRCLR), U5.16 (VCC)

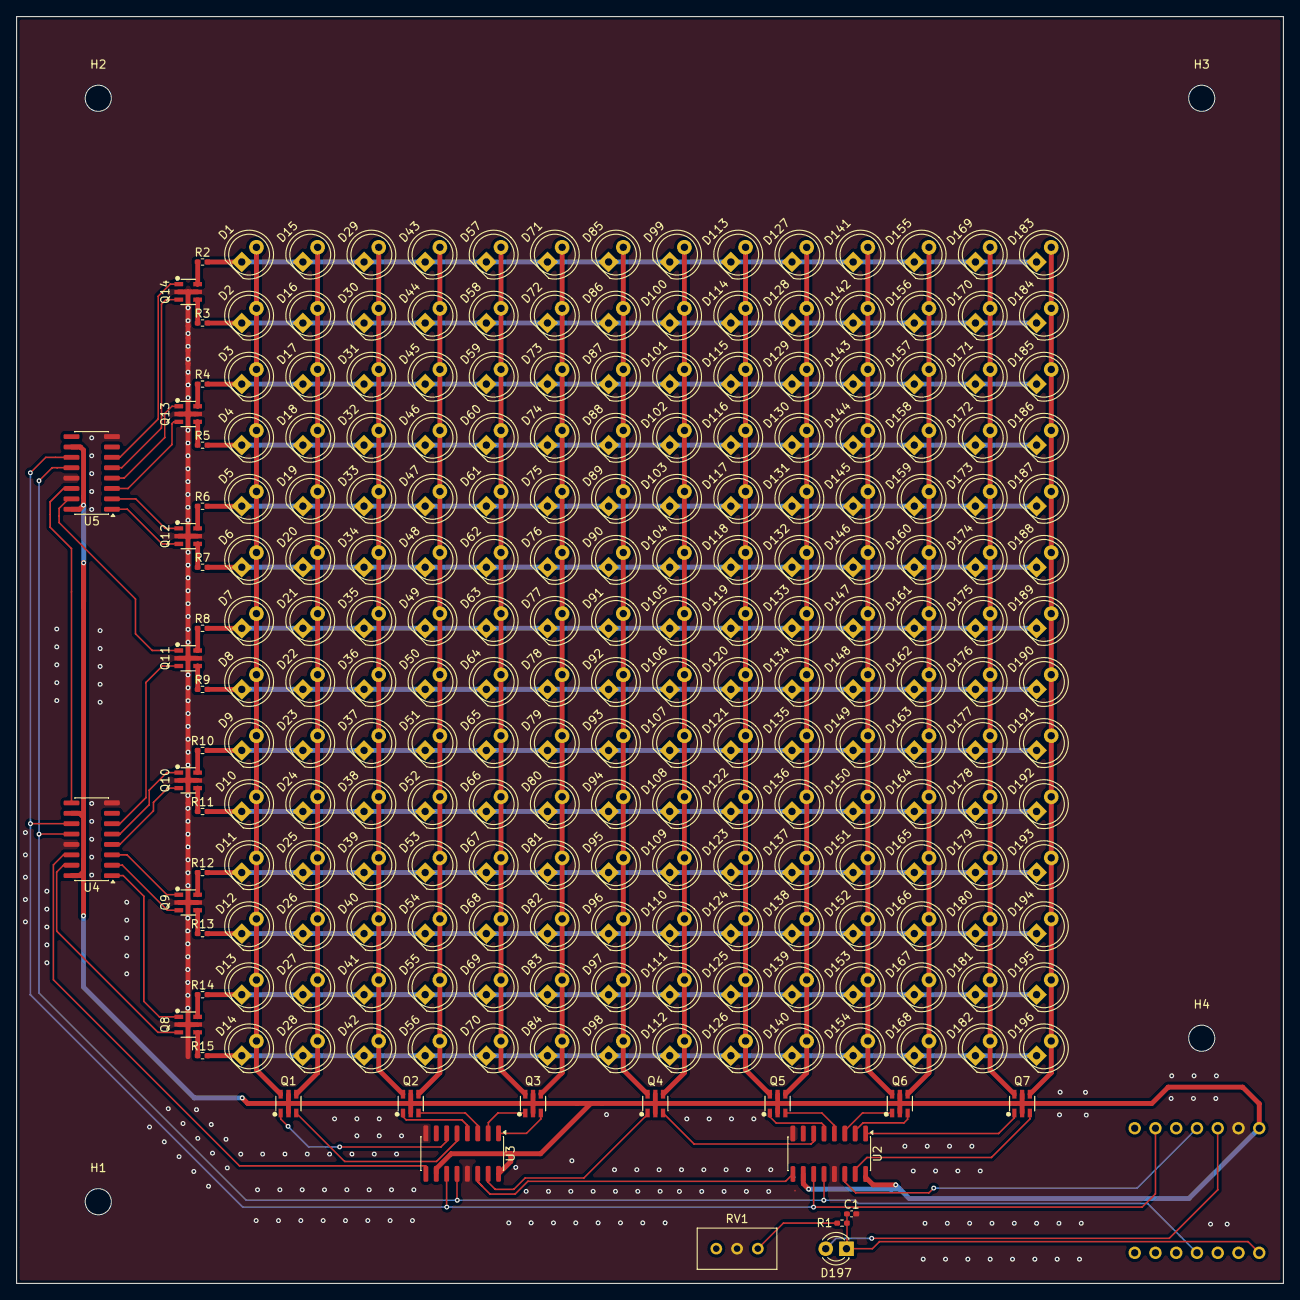
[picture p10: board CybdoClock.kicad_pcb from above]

Board: 2 copper layers, 155.0 x 155.0 mm, 237 parts (1 on the bottom side), 81 nets.

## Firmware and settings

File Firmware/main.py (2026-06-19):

import time
import board
import digitalio
import adafruit_74hc595
import socketpool
import adafruit_ntp
import wifi
import os
import asyncio



latch_pin = digitalio.DigitalInOut(board.D3)
sr = adafruit_74hc595.ShiftRegister74HC595(board.SPI(), latch_pin)

rows = [sr.get_pin(14), sr.get_pin(13), sr.get_pin(12), sr.get_pin(11), sr.get_pin(10), sr.get_pin(9), sr.get_pin(8),
        sr.get_pin(6), sr.get_pin(5), sr.get_pin(4), sr.get_pin(3), sr.get_pin(2), sr.get_pin(1), sr.get_pin(0)]

cols = [sr.get_pin(30), sr.get_pin(29), sr.get_pin(28), sr.get_pin(27), sr.get_pin(26), sr.get_pin(25), sr.get_pin(24),
        sr.get_pin(22), sr.get_pin(21), sr.get_pin(20), sr.get_pin(19), sr.get_pin(18), sr.get_pin(17), sr.get_pin(16)]




'''
C	Y	B	D	O	C	L	O	C	K	N	A	U	S
I	T	C	I	S	Y	T	E	N	F	O	R	T	Y
T	W	E	N	T	Y	B	T	H	I	R	T	Y	D
H	A	L	F	I	F	T	Y	O	T	W	O	N	E
Q	U	A	R	T	E	R	S	I	X	F	O	U	R
C	S	E	V	E	N	I	N	E	L	E	V	E	N
T	H	R	E	E	I	G	H	T	W	E	L	V	E
T	E	E	N	C	F	I	V	E	E	T	O	K	V
T	H	A	C	K	P	C	L	U	B	P	A	S	T
T	E	N	I	N	E	I	G	H	T	W	O	N	E
O	F	O	U	R	S	E	V	E	N	S	I	X	N
F	I	V	E	L	E	V	E	N	T	H	R	E	E
T	W	E	L	V	E	E	O	N	C	L	O	C	K
P	T	F	A	L	L	O	U	T	A	P	N	D	K
'''



clock_hour_pos = {
    
    1: {11:9, 12:9, 13:9},
    2: {9:9, 10:9, 11:9},
    3: {9:11, 10:11, 11:11, 12:11, 13:11},
    4: {1:10, 2:10, 3:10, 4:10},
    5: {0:11, 1:11, 2:11, 3:11},
    6: {10:10, 11:10, 12:10},
    7: {5:10, 6:10, 7:10, 8:10, 9:10},
    8: {5:9, 6:9, 7:9, 8:9, 9:9},
    9: {2:9, 3:9, 4:9, 5:9},
    10: {0:9, 1:9, 2:9},
    11: {3:11, 4:11, 5:11, 6:11, 7:11, 8:11},
    12: {0:12, 1:12, 2:12, 3:12, 4:12, 5:12}
    
}


clock_minute_pos = {
        # minute: {col: row, col: row, ...}
    0: {7:12, 9:12, 10:12, 11:12, 12:12, 13:12},
    1: {11:3, 12:3, 13:3},
    2: {9:3, 10:3, 11:3},
    3: {0:6, 1:6, 2:6, 3:6, 4:6},
    4: {10:4, 11:4, 12:4, 13:4},
    5: {5:7, 6:7, 7:7, 8:7},
    6: {7:4, 8:4, 9:4},
    7: {1:5, 2:5, 3:5, 4:5, 5:5},
    8: {4:6, 5:6, 6:6, 7:6, 8:6},
    9: {5:5, 6:5, 7:5, 8:5},
    10: {6:1, 7:1, 8:1},
    11: {8:5, 9:5, 10:5, 11:5, 12:5, 13:5},
    12: {8:6, 9:6, 10:6, 11:6, 12:6, 13:6}, 
    13: {7:2, 8:2, 9:2, 10:2},
    14: {10:4, 11:4, 12:4, 13:4},
    15: {3:3, 4:3, 5:3},
    16: {7:4, 8:4, 9:4},
    17: {1:5, 2:5, 3:5, 4:5, 5:5},
    18: {4:6, 5:6, 6:6, 7:6},
    19: {5:5, 6:5, 7:5},
    20: {0:2, 1:2, 2:2, 3:2, 4:2, 5:2},
    30: {7:2, 8:2, 9:2, 10:2, 11:2, 12:2},
    40: {9:1, 10:1, 11:1, 12:1, 13:1},
    50: {3:3, 4:3, 5:3, 6:3, 7:3}
}

clock_word_pos = {
    "it is": {0:1, 1:1, 3:1, 4:1},
    "half": {0:3, 1:3, 2:3, 3:3},
    "quarter": {0:4, 1:4, 2:4, 3:4, 4:4, 5:4, 6:4},
    "quarters": {0:4, 1:4, 2:4, 3:4, 4:4, 5:4, 6:4, 7:4},
    "a": {1:3},
    "to": {10:7, 11:7},
    "past": {10:8, 11:8, 12:8, 13:8},
    "oclock": {7:12, 9:12, 10:12, 11:12, 12:12, 13:12},
    "teen": {0:7, 1:7, 2:7, 3:7}
    
}

latch_pin = digitalio.DigitalInOut(board.D3)
sr = adafruit_74hc595.ShiftRegister74HC595(board.SPI(), latch_pin)

rowsarr = [sr.get_pin(14), sr.get_pin(13), sr.get_pin(12), sr.get_pin(11), sr.get_pin(10), sr.get_pin(9), sr.get_pin(8),
        sr.get_pin(6), sr.get_pin(5), sr.get_pin(4), sr.get_pin(3), sr.get_pin(2), sr.get_pin(1), sr.get_pin(0)]

colsarr = [sr.get_pin(30), sr.get_pin(29), sr.get_pin(28), sr.get_pin(27), sr.get_pin(26), sr.get_pin(25), sr.get_pin(24),
        sr.get_pin(22), sr.get_pin(21), sr.get_pin(20), sr.get_pin(19), sr.get_pin(18), sr.get_pin(17), sr.get_pin(16)]


refreshtime = 0.02




async def draw_row(row, columns):
    rowsarr[row].value = True
    for column in columns:
        colsarr[column].value = True
    await asyncio.sleep(refreshtime)
    rowsarr[row].value = False
    for column in columns:
        colsarr[column].value = False

async def draw_matrix(matrix):
    for row in matrix.keys():
        columns = []
        for column in range(14):
            if matrix[row][column] == 1:
                columns.append(column)
        await draw_row(row, columns)
    


def parse_time(ntp):
    currenthour = ntp.tm_hour
    currentminute = ntp.tm_min
    
    matrix = {row: [0] * 14 for row in range(14)}

    def add_positions(position_map):
        if position_map is None:
            return
        for column, row in position_map.items():
            matrix[row][column] = 1

    if currentminute > 30:
        currenthour = (currenthour + 1) % 12
        if currenthour == 0:
            currenthour = 12
        currentminute = 60 - currentminute
        minute_tens = currentminute // 10
        minute_ones = currentminute % 10
        if currentminute != 0:
            add_positions(clock_word_pos["to"])
    else:
        minute_tens = currentminute // 10
        minute_ones = currentminute % 10
        if currentminute != 0:
            add_positions(clock_word_pos["past"])

    if currentminute == 15:
        add_positions(clock_word_pos["a"])
        add_positions(clock_word_pos["quarter"])
    elif currentminute == 30:
        add_positions(clock_word_pos["half"])
    elif currentminute in clock_minute_pos:
        add_positions(clock_minute_pos[currentminute])
    else:
        add_positions(clock_minute_pos[minute_tens * 10])
        add_positions(clock_minute_pos[minute_ones])

    if currentminute in [13, 14, 16, 17, 18, 19]:
        add_positions(clock_word_pos["teen"])


    

    add_positions(clock_word_pos["it is"])
    add_positions(clock_hour_pos[currenthour])



    return matrix


async def main():
    pool = socketpool.SocketPool(wifi.radio)
    ntp = adafruit_ntp.NTP(pool, tz_offset=int(os.getenv('CIRCUITPY_TZ_OFFSET')), cache_seconds=int(os.getenv('CIRCUITPY_NTP_CACHE_SECONDS')), server=os.getenv('CIRCUITPY_NTP_SERVER'))
    while True:
        leds = parse_time(ntp.datetime)
    
        await draw_matrix(leds)


asyncio.run(main())
        
    

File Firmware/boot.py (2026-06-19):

import asyncio
import time
import board
import digitalio
import adafruit_74hc595


import os, wifi




latch_pin = digitalio.DigitalInOut(board.D3)
sr = adafruit_74hc595.ShiftRegister74HC595(board.SPI(), latch_pin)

rowsarr = [sr.get_pin(14), sr.get_pin(13), sr.get_pin(12), sr.get_pin(11), sr.get_pin(10), sr.get_pin(9), sr.get_pin(8),
        sr.get_pin(6), sr.get_pin(5), sr.get_pin(4), sr.get_pin(3), sr.get_pin(2), sr.get_pin(1), sr.get_pin(0)]

colsarr = [sr.get_pin(30), sr.get_pin(29), sr.get_pin(28), sr.get_pin(27), sr.get_pin(26), sr.get_pin(25), sr.get_pin(24),
        sr.get_pin(22), sr.get_pin(21), sr.get_pin(20), sr.get_pin(19), sr.get_pin(18), sr.get_pin(17), sr.get_pin(16)]


refreshtime = 0.02






async def draw_row(row, columns):
    rowsarr[row].value = True
    for column in columns:
        colsarr[column].value = True
    await asyncio.sleep(refreshtime)
    rowsarr[row].value = False
    for column in columns:
        colsarr[column].value = False

async def draw_matrix(matrix):
    for row in matrix.keys():
        columns = []
        for column in range(14):
            if matrix[row][column] == 1:
                columns.append(column)
        await draw_row(row, columns)
    

    


# draw CYBDOCLOCK, HACK CLUB, FALLOUT

startup_matrix = {
    0: [1,0,0,0,0,0,0,0,0,0,0,0,0,0],
    1: [1,0,0,0,0,0,0,0,1,0,0,0,0,0],
    2: [1,0,0,0,0,0,0,0,1,0,0,0,0,1],
    3: [1,0,0,0,0,0,0,0,1,0,0,0,0,1],
    4: [1,0,0,0,0,0,0,0,1,0,0,0,0,1],
    5: [1,0,0,0,0,0,0,0,0,0,0,0,0,1],
    6: [1,0,0,0,0,0,0,0,1,0,0,0,0,1],
    7: [1,0,0,0,0,0,0,0,1,0,0,0,0,1],
    8: [1,0,0,0,0,0,0,0,1,0,0,0,0,1],
    9: [1,0,0,0,0,0,0,0,1,0,0,0,0,0],
    10: [0,0,0,0,0,0,0,0,0,0,0,0,0,0],
    11: [0,0,0,0,0,0,0,0,0,0,0,0,0,0],
    12: [0,0,0,0,0,0,0,0,0,0,0,0,0,0],
    13: [0,0,0,0,0,0,0,0,0,0,0,0,0,0],
}


no_wifi_matrix = {
 0: [0, 0, 0, 0, 1, 0, 0, 0, 0, 0, 0, 0, 0, 0],
 1: [0, 0, 0, 1, 0, 0, 0, 1, 0, 0, 0, 0, 0, 0],
 2: [0, 0, 1, 0, 0, 0, 1, 0, 0, 0, 0, 0, 0, 0],
 3: [0, 0, 1, 0, 0, 0, 1, 0, 0, 1, 0, 0, 0, 0],
 4: [0, 1, 0, 0, 0, 1, 0, 0, 1, 0, 0, 0, 0, 0],
 5: [0, 1, 0, 0, 0, 1, 0, 0, 1, 0, 0, 1, 0, 0],
 6: [0, 1, 0, 0, 0, 1, 0, 0, 1, 0, 1, 1, 1, 0],
 7: [0, 1, 0, 0, 0, 1, 0, 0, 1, 0, 1, 1, 1, 0],
 8: [0, 1, 0, 0, 0, 1, 0, 0, 1, 0, 0, 1, 0, 0],
 9: [0, 1, 0, 0, 0, 1, 0, 0, 1, 0, 0, 0, 0, 1],
 10: [0, 0, 1, 0, 0, 0, 1, 0, 0, 1, 0, 0, 0, 0],
 11: [0, 0, 1, 0, 0, 0, 1, 0, 0, 0, 0, 0, 0, 0],
 12: [0, 0, 0, 1, 0, 0, 0, 1, 0, 0, 0, 0, 0, 0],
 13: [0, 0, 0, 0, 1, 0, 0, 0, 0, 0, 0, 0, 0, 0]}




async def main():
    
    if os.getenv('CIRCUITPY_WIFI_SSID') is None or os.getenv('CIRCUITPY_WIFI_PASSWORD') is None:
        print("no wifi creds")
        while True:
            await draw_matrix(no_wifi_matrix)
        
        
        
        
    print("connecting...")
    await wifi.radio.connect(ssid=os.getenv('CIRCUITPY_WIFI_SSID'),
                            password=os.getenv('CIRCUITPY_WIFI_PASSWORD'))

    print("my IP addr:", wifi.radio.ipv4_address)
    
    start_time = time.monotonic()
    while True:
        if start_time - time.monotonic() < 5:
            await draw_matrix(startup_matrix)
        else:
            break


asyncio.run(main())

    

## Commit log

2026-06-15 finished the pcb
    [CybdoClock.kicad_pcb, CybdoClock.kicad_sch, layouts.xlsx]
2026-06-16 updated mounting holes and some 3d models
    [CybdoClock.kicad_pcb]
2026-06-17 use built in serial pins, start on firmware using circuitpython
    [CybdoClock.kicad_pcb, CybdoClock.kicad_sch, layouts.xlsx]
2026-06-18 firmware done, centered leds positioning
    [CybdoClock.kicad_pcb, Seeed Studio XIAO ESP32-C6.step, layouts.xlsx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]
2026-06-19 added 3d models, renders, bom, finalised firmware, pcb
    [Clock Faceplate.step, Faceplate Template.step, Untitled.blend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]
2026-06-19 redo the timer
2026-06-19 add esp32 to bom
    [bom.csv]
2026-06-24 bom total
    [bom.csv]
2026-06-24 forgor a comma
    [bom.csv]
